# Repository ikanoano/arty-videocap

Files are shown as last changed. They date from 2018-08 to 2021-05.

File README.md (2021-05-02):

# arty-videocap
This is a video capture/repeater implementation on Arty-A7 the FPGA board.  
An extender board adds In/Out video ports which enables passthrough capability so that there is no delay from video source to monitor.
Captured video is sent as Motion JPEG (MJPEG) format over udp just like common cameras do.  
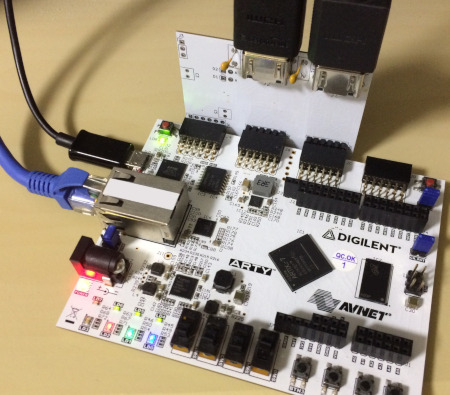
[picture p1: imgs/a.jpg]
board


Right: No delay video from a game console  
Left: Video received in PC  
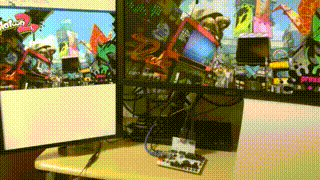
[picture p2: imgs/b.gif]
capturing


### RTL
hdl/MJPG_ENCODER.v and hdl/COMPONENT_ENCODER.v represent realtime MJPEG encoder.  
There is an equivalent implementation in C [here](https://github.com/ikanoano/bmp2jpeg).

### Extender board
Schematic and pcb layout are in pcb/

## How to use
### Hardware setup
1. Connect Arty, Video source, monitor and PC like below imege
2. Turn Arty and video source on
3. Once LD0, LD1 and LD2 grow, Arty starts repeating video signal to your monitor
4. Turn toggle switch SW0 on
5. Arty starts sending captured video as MJPEG stream to your PC
6. Receive MJPEG in PC using ffplay.  
`$ ffplay -f mjpeg -framerate 30 -i udp://127.0.0.1:4096`

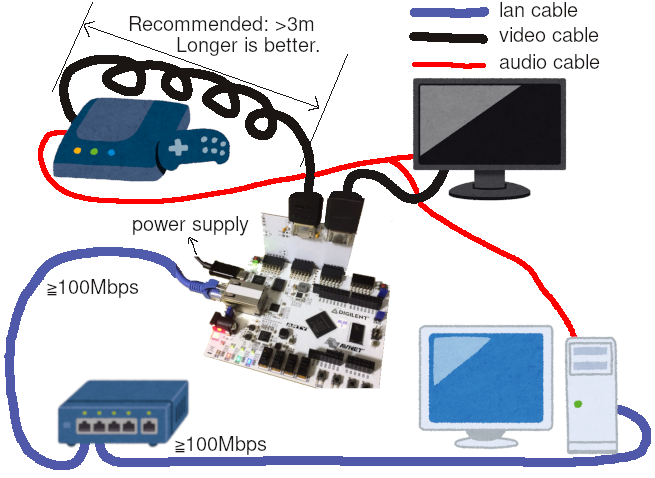
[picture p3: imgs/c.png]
network

images:[いらすとや](https://www.irasutoya.com/)

Confirmed Arty could repeat/capture 720p video sent from nintendo switch.

Your ethernet LAN hub should support jumbo frame, or jumbo frame must be disabled in RTL.  
Maybe reverting [this commit](https://github.com/ikanoano/ArtyEtherentTX/commit/a2c306d0d0775d83d8b783aa43c7d5825ad52278) works.

## How to build
### Extender board
1. Open pcb/pass_through/pass_through.pro with [kicad](http://kicad-pcb.org/)
2. Produce garbar files to order it to manufacturer. Thinner(≦0.8mm) board is better
3. Solder JP1-4, J1-2, F1-2, C1-2, C5-8, R9-18, JB1 and JC1
4. Attatch the extender board to Arty-A7 JB and JC

### RTL/Arty
1. [Install Vivado and Digilent Board Files.](https://reference.digilentinc.com/vivado/installing-vivado/start)
2. Create an RTL project. Target board should be Arty A35T
3. Import files under hdl/synth_capture/
4. [Edit destination IP address and MAC address here](https://github.com/ikanoano/ArtyEtherentTX/blob/4adc945a84c8c2099e27458f0dac0a361e1121d6/hdl/ethernet_test.vhd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)
5. Manually create 3 clocking modules using cloking wizard in vivado. See PASS_THROUGH.v
6. Generate bitfile
7. [Programming Arty using Quad SPI](https://reference.digilentinc.com/learn/programmable-logic/tutorials/arty-programming-guide/start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)

## How to test MJPEG encoder RTL
Required: iverilog
1. Checkout [framehex branch at bmp2jpeg repo](https://github.com/ikanoano/bmp2jpeg/tree/output_framehex) and produce an executable
2. Convert any (small) image using 1. and you will get a simulated video signal in /tmp/frame.hex
3. Run make in hdl/
3. Run ./isim and you will get /tmp/frame.jpg, which is output from simulation. Check if it's valid

See how output jpeg will change if you reduce the value of DCT_TH_Y and DCT_TH_C in hdl/MJPG_ENCODER.v .

## License
### Except vivado-library/ and ArtyEtherentTX/
Copyright (c) 2018 ikanoano  
Released under the [MIT](https://opensource.org/licenses/mit-license.php) license

### vivado-library
Copyright (c) 2017 Digilent  
Released under the [MIT](https://opensource.org/licenses/mit-license.php) license  
See hdl/vivado-library/License.txt

## References
* [LucidScience - Build the VGA VIDEO GENERATOR](http://www.lucidscience.com/pro-vga%20video%20generator-1.aspx)
* [Xilinx - XAPP495 Implementing a TMDS Video Interface in the Spartan-6 FPGA](https://www.xilinx.com/support/documentation/application_notes/xapp495_S6TMDS_Video_Interface.pdf)
* [HDMI-NAVI.com - TMDS(Transition Minimized Differential Signaling)](http://www.hdmi-navi.com/tmds/)
* [bmp2jpeg](https://github.com/ikanoano/bmp2jpeg)

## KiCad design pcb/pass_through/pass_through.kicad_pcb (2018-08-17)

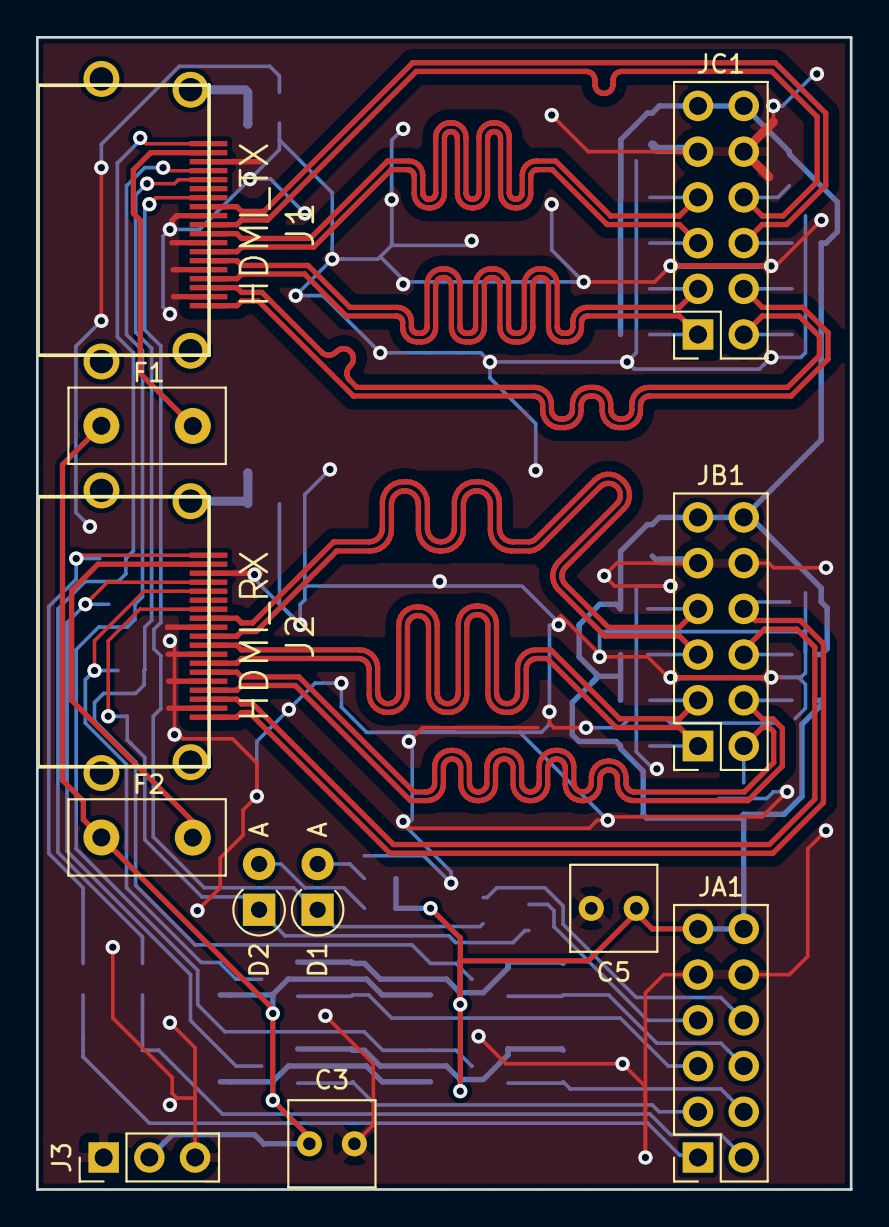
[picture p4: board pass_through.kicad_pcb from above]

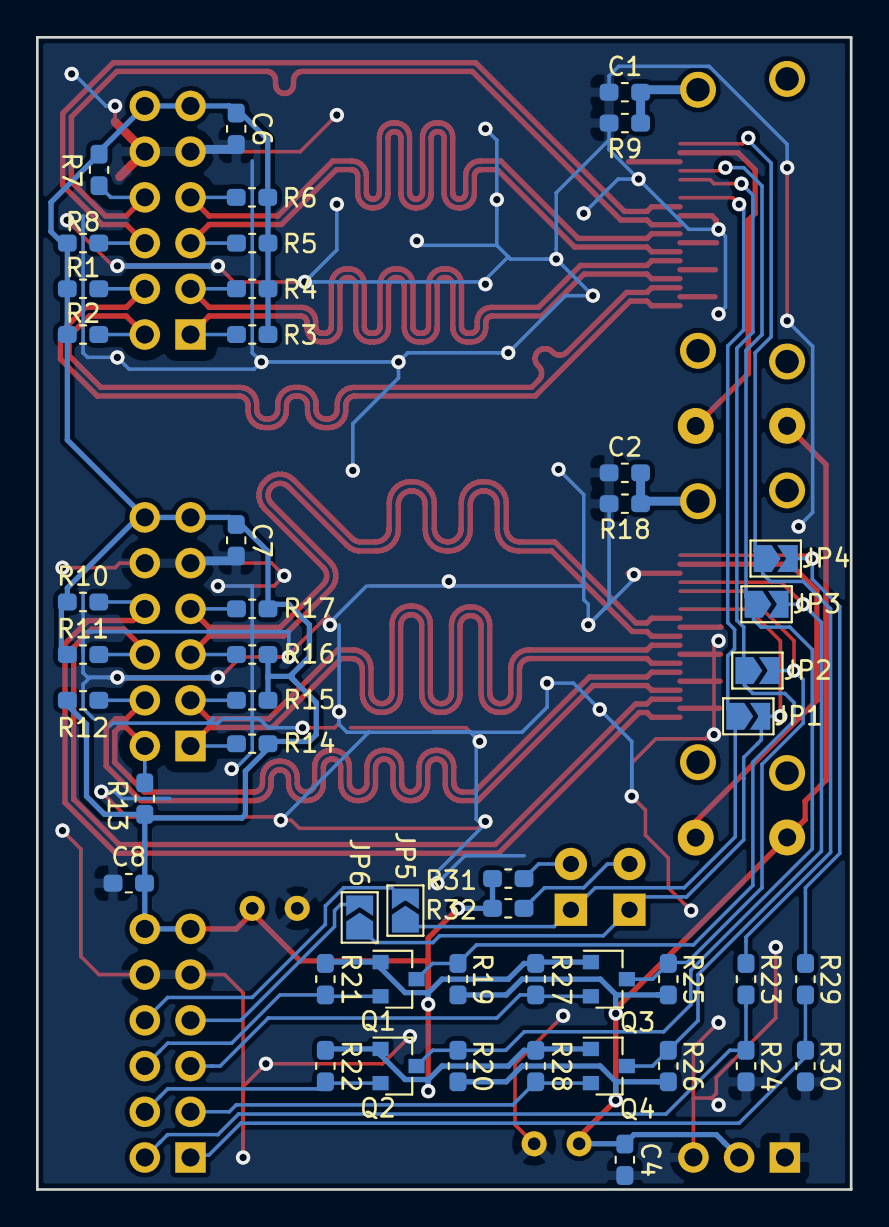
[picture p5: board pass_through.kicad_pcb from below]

Board: 2 copper layers, 45.2 x 64.0 mm, 60 parts (48 on the bottom side), 41 nets.

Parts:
C1, C2: 1000p; C_0603_1608Metric_Pad1.05x0.95mm_HandSolder
C3, C5: 10u; C_Rect_L4.6mm_W4.6mm_P2.50mm_MKS02_FKP02
C4, C6, C7, C8: 0.1u; C_0603_1608Metric_Pad1.05x0.95mm_HandSolder
D1, D2: D; D_A-405_P2.54mm_Vertical_AnodeUp
F1, F2: Polyfuse_Small; Fuse_Littelfuse_395Series
J1: HDMI_TX; FCI_10029449-11[13]RLF
J2: HDMI_RX; FCI_10029449-11[13]RLF
J3: Conn_01x03; PinHeader_1x03_P2.54mm_Vertical
JA1: Conn_02x06_Top_Bottom; Pmod_V
JB1: Conn_02x06_Top_Bottom; Pmod_V
JC1: Conn_02x06_Top_Bottom; Pmod_V
JP1, JP5, JP6: J_CEC; SolderJumper-2_P1.3mm_Open_TrianglePad1.0x1.5mm
JP2: J_SCL; SolderJumper-2_P1.3mm_Open_TrianglePad1.0x1.5mm
JP3: J_SDA; SolderJumper-2_P1.3mm_Open_TrianglePad1.0x1.5mm
JP4: J_HPD; SolderJumper-2_P1.3mm_Open_TrianglePad1.0x1.5mm
Q1, Q2, Q3, Q4: Q_NMOS_GSD; SOT-23
R1, R2, R3, R4, R5, R6, R7, R8, R10, R11, R12, R13, R14, R15, R16, R17: 50; R_0603_1608Metric_Pad1.05x0.95mm_HandSolder
R9, R18: 1M; R_0603_1608Metric_Pad1.05x0.95mm_HandSolder
R19, R20, R21, R22, R25, R26, R27, R28, R30: 2k; R_0603_1608Metric_Pad1.05x0.95mm_HandSolder
R23: 22k; R_0603_1608Metric_Pad1.05x0.95mm_HandSolder
R24: 33k; R_0603_1608Metric_Pad1.05x0.95mm_HandSolder
R29: 1k; R_0603_1608Metric_Pad1.05x0.95mm_HandSolder
R31, R32: 27k; R_0603_1608Metric_Pad1.05x0.95mm_HandSolder

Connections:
+5V: C3.1, C4.1, F1.1, F2.1, J3.2, R19.1, R20.1, R25.1, R26.1
/R0_N: J2.9, JB1.2, R15.2
/R0_P: J2.7, JB1.1, R14.2
/R1_N: J2.6, JB1.7, R13.2
/R1_P: J2.4, JB1.8, R12.2
/R2_N: J2.3, JB1.9, R11.2
/R2_P: J2.1, JB1.10, R10.2
/RCEC: D2.1, J2.13, JP1.2, JP6.1
/RCEC3.3: JA1.4, JP6.2
/RC_N: J2.12, JB1.4, R17.2
/RC_P: J2.10, JB1.3, R16.2
/RHPD: J2.19, JP4.2, R29.2
/RHPD3.3: JA1.1, R29.1, R30.2
/RSCL: J2.15, JP2.2, Q3.3, R25.2
/RSCL3.3: JA1.3, Q3.2, R27.2
/RSDA: J2.16, JP3.2, Q4.3, R26.2
/RSDA3.3: JA1.2, Q4.2, R28.2
/RSH: C2.2, J2.SH, R18.1
/T0_N: J1.9, JC1.4, R6.2
/T0_P: J1.7, JC1.3, R5.2
/T1_N: J1.6, JC1.2, R4.2
/T1_P: J1.4, JC1.1, R3.2
/T2_N: J1.3, JC1.7, R2.2
/T2_P: J1.1, JC1.8, R1.2
/TCEC: D1.1, J1.13, JP1.1, JP5.1
/TCEC3.3: JA1.10, JP5.2
/TC_N: J1.12, JC1.9, R8.2
/TC_P: J1.10, JC1.10, R7.2
/THPD: J1.19, JP4.1, R23.2
/THPD3.3: JA1.7, R23.1, R24.2
/TSCL: J1.15, JP2.1, Q1.3, R19.2
/TSCL3.3: JA1.9, Q1.2, R21.2
/TSDA: J1.16, JP3.1, Q2.3, R20.2
/TSDA3.3: JA1.8, Q2.2, R22.2
/TSH: C1.2, J1.SH, R9.1
GND: C1.1, C2.1, C3.2, C4.2, C5.2, C6.2, C7.2, C8.2, J1.2, J1.5, J1.8, J1.11, J1.17, J2.2, J2.5, J2.8, J2.11, J2.17, J3.1, J3.3, JA1.5, JA1.11, JB1.5, JB1.11, JC1.5, JC1.11, R9.2, R18.2, R24.1, R30.1
unnamed: D1.2, R31.2
unnamed: D2.2, R32.2
unnamed: F1.2, J1.18
unnamed: F2.2, J2.18
VCC: C5.1, C6.1, C7.1, C8.1, JA1.6, JA1.12, JB1.6, JB1.12, JC1.6, JC1.12, Q1.1, Q2.1, Q3.1, Q4.1, R1.1, R2.1, R3.1, R4.1, R5.1, R6.1, R7.1, R8.1, R10.1, R11.1, R12.1, R13.1, R14.1, R15.1, R16.1, R17.1, R21.1, R22.1, R27.1, R28.1, R31.1, R32.1

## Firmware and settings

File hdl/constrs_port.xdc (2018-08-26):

set_property IOSTANDARD LVCMOS33 [get_ports {led[4]}]
set_property IOSTANDARD LVCMOS33 [get_ports {led[5]}]
set_property IOSTANDARD LVCMOS33 [get_ports {led[6]}]
set_property IOSTANDARD LVCMOS33 [get_ports {led[7]}]
set_property IOSTANDARD TMDS_33 [get_ports {tmds_tx_p[0]}]
set_property IOSTANDARD TMDS_33 [get_ports {tmds_tx_p[1]}]
set_property IOSTANDARD TMDS_33 [get_ports {tmds_tx_p[2]}]
set_property IOSTANDARD TMDS_33 [get_ports {tmds_tx_p[3]}]
set_property IOSTANDARD TMDS_33 [get_ports {tmds_rx_p[3]}]
set_property IOSTANDARD TMDS_33 [get_ports {tmds_rx_p[2]}]
set_property IOSTANDARD TMDS_33 [get_ports {tmds_rx_p[1]}]
set_property IOSTANDARD TMDS_33 [get_ports {tmds_rx_p[0]}]
set_property IOSTANDARD LVCMOS33 [get_ports rst_raw_n]
set_property IOSTANDARD LVCMOS33 [get_ports scl_tx]
set_property IOSTANDARD LVCMOS33 [get_ports sda_tx]
set_property IOSTANDARD LVCMOS33 [get_ports hpd_tx]
set_property IOSTANDARD LVCMOS33 [get_ports scl_rx]
set_property IOSTANDARD LVCMOS33 [get_ports sda_rx]
set_property IOSTANDARD LVCMOS33 [get_ports hpd_rx]
set_property IOSTANDARD LVCMOS33 [get_ports {btn[3]}]
set_property IOSTANDARD LVCMOS33 [get_ports {btn[2]}]
set_property IOSTANDARD LVCMOS33 [get_ports {btn[1]}]
set_property IOSTANDARD LVCMOS33 [get_ports {btn[0]}]
set_property IOSTANDARD LVCMOS33 [get_ports {sw[3]}]
set_property IOSTANDARD LVCMOS33 [get_ports {sw[2]}]
set_property IOSTANDARD LVCMOS33 [get_ports {sw[1]}]
set_property IOSTANDARD LVCMOS33 [get_ports {sw[0]}]
set_property IOSTANDARD LVCMOS33 [get_ports clk_src_raw]


set_property PACKAGE_PIN H5  [get_ports {led[4]}]
set_property PACKAGE_PIN J5  [get_ports {led[5]}]
set_property PACKAGE_PIN T9  [get_ports {led[6]}]
set_property PACKAGE_PIN T10 [get_ports {led[7]}]
set_property PACKAGE_PIN V10 [get_ports {tmds_tx_p[0]}]
set_property PACKAGE_PIN U12 [get_ports {tmds_tx_p[1]}]
# inv
set_property PACKAGE_PIN U14 [get_ports {tmds_tx_p[2]}]
# inv
set_property PACKAGE_PIN T13 [get_ports {tmds_tx_p[3]}]
set_property PACKAGE_PIN D15 [get_ports {tmds_rx_p[3]}]
set_property PACKAGE_PIN E15 [get_ports {tmds_rx_p[0]}]
# inv
set_property PACKAGE_PIN J17 [get_ports {tmds_rx_p[1]}]
# inv
set_property PACKAGE_PIN K15 [get_ports {tmds_rx_p[2]}]
set_property PACKAGE_PIN C2  [get_ports rst_raw_n]
set_property PACKAGE_PIN G13 [get_ports hpd_rx]
set_property PACKAGE_PIN B11 [get_ports sda_rx]
set_property PACKAGE_PIN A11 [get_ports scl_rx]
set_property PACKAGE_PIN D13 [get_ports hpd_tx]
set_property PACKAGE_PIN B18 [get_ports sda_tx]
set_property PACKAGE_PIN A18 [get_ports scl_tx]
set_property PACKAGE_PIN B8  [get_ports {btn[3]}]
set_property PACKAGE_PIN B9  [get_ports {btn[2]}]
set_property PACKAGE_PIN C9  [get_ports {btn[1]}]
set_property PACKAGE_PIN D9  [get_ports {btn[0]}]
set_property PACKAGE_PIN A10 [get_ports {sw[3]}]
set_property PACKAGE_PIN C10 [get_ports {sw[2]}]
set_property PACKAGE_PIN C11 [get_ports {sw[1]}]
set_property PACKAGE_PIN A8  [get_ports {sw[0]}]
set_property PACKAGE_PIN E3  [get_ports clk_src_raw]

set_property -dict { PACKAGE_PIN E1    IOSTANDARD LVCMOS33 } [get_ports { led0[2] }];
set_property -dict { PACKAGE_PIN F6    IOSTANDARD LVCMOS33 } [get_ports { led0[1] }];
set_property -dict { PACKAGE_PIN G6    IOSTANDARD LVCMOS33 } [get_ports { led0[0] }];
set_property -dict { PACKAGE_PIN G4    IOSTANDARD LVCMOS33 } [get_ports { led1[2] }];
set_property -dict { PACKAGE_PIN J4    IOSTANDARD LVCMOS33 } [get_ports { led1[1] }];
set_property -dict { PACKAGE_PIN G3    IOSTANDARD LVCMOS33 } [get_ports { led1[0] }];
set_property -dict { PACKAGE_PIN H4    IOSTANDARD LVCMOS33 } [get_ports { led2[2] }];
set_property -dict { PACKAGE_PIN J2    IOSTANDARD LVCMOS33 } [get_ports { led2[1] }];
set_property -dict { PACKAGE_PIN J3    IOSTANDARD LVCMOS33 } [get_ports { led2[0] }];
set_property -dict { PACKAGE_PIN K2    IOSTANDARD LVCMOS33 } [get_ports { led3[2] }];
set_property -dict { PACKAGE_PIN H6    IOSTANDARD LVCMOS33 } [get_ports { led3[1] }];
set_property -dict { PACKAGE_PIN K1    IOSTANDARD LVCMOS33 } [get_ports { led3[0] }];

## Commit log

2018-08-17 add pcb
    [pass_through.kicad_pcb, pass_through.sch]
2018-08-20 add stuff byte insertion
2018-08-20 fix stuff byte inserter
2018-08-28 add frame rate limitter, enlarge ethernet FIFO
2018-08-28 jumbo frame
2018-08-30 add switches for ethernet enable and vsync invert
